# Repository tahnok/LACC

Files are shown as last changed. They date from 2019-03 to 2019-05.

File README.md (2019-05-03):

# L.A.C.C

## Laser-cut ATX Computer Case

This is a full sized ATX computer case you can laser cut (and probably cut using a CNC but I don't have one of those)

It should fit any ATX compliant motherboard, but I've only tried the one motherboard I have.

It has space for 3x 3.5" hard drives and a 2.5" hard drive, which are held by seperate 3d printed modules.

The entire design was done in Fusion 360. You can view it / download it [here](https://a360.co/2EToDJn) or use the LACC.f3z file attached.

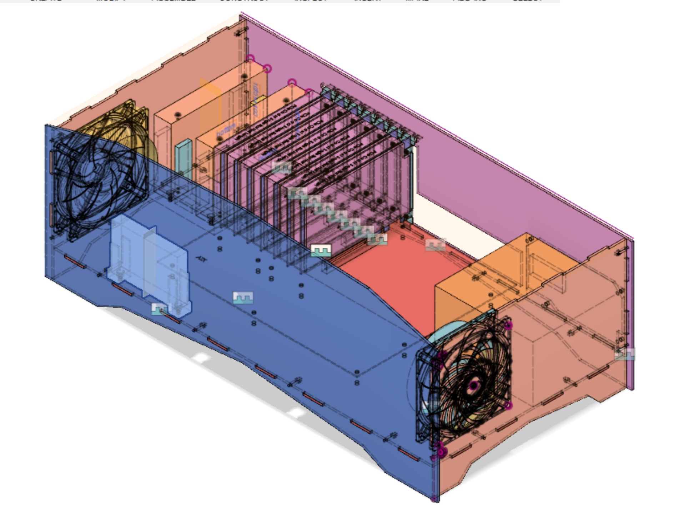
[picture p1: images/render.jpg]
render of case from fusion 360


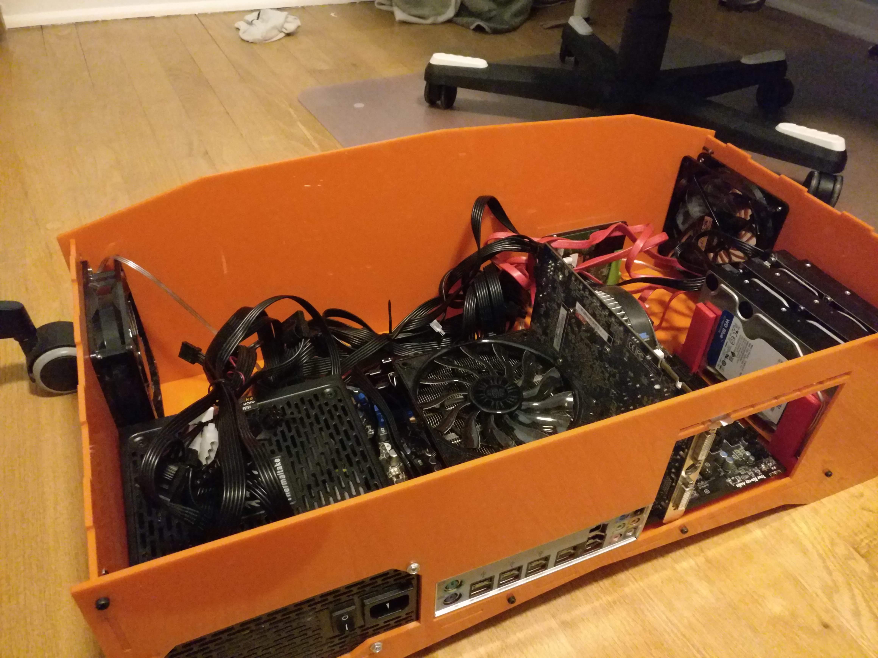
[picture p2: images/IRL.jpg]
actual built case


[more photos](https://photos.app.goo.gl/nMJByEWeSShFq6Pd6)

## Materials

### Case 
 - 5x sheets of 24" x 12" sheet of 1/8" or 3mm acrylic or MDF 
 - 26x M3 nuts
 - 20x M3x16 screws (for holding case together)
 - 6x M3x12 standoffs (for motherboard)
 - 6x M3x4 screws (for standoffs)
 - 2x 120mm Computer Fan
 - 4x 6-32 screws for ATX power supply

### Hard Drive Bays
 - 2x of the 3.5" drive holder parts
 - 2x of the 2.5" drive holder parts
 - 6x M3x10 screws
 - 6x M3 nuts

## Models Used

 - [Accurate Blank Motherboard & PCIe Card Models](https://smallformfactor.net/forum/resources/accurate-blank-motherboard-pcie-card-models.25/) by subtec
 - [120mm PC Case Fan](https://grabcad.com/library/120mm-pc-case-fan-1) by 
Ollie Keattch
 - Power supply (mine)
 - Hard Drive 2.5" and 3.5" (mine)

## License

 [Creative Commons Attribution-ShareAlike 4.0 International](https://creativecommons.org/licenses/by-sa/4.0/)

 You are free to use, sell and remix freely as long as any modifications you make are also shared under this same license

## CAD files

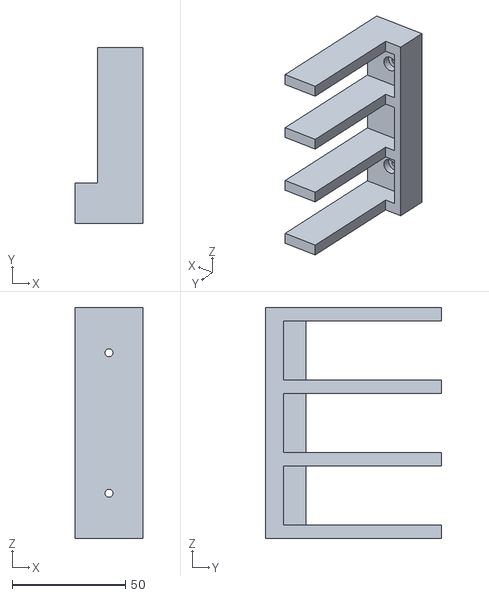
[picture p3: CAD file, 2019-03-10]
hard drive parts/hard drive holder 3-5.stl
30.0 x 78.0 x 102.1

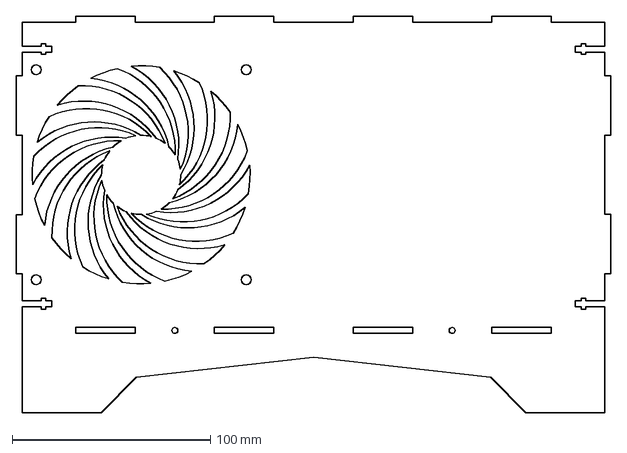
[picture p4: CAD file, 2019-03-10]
side.dxf
300.0 x 200.0 mm

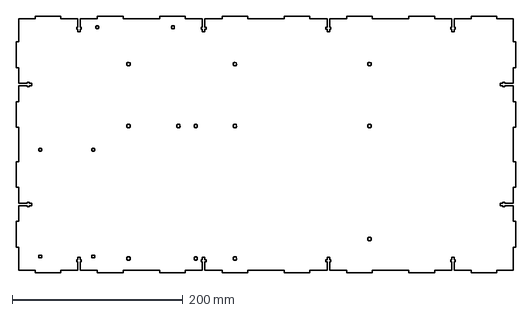
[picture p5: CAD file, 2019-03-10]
bottom.dxf
584.0 x 300.0 mm

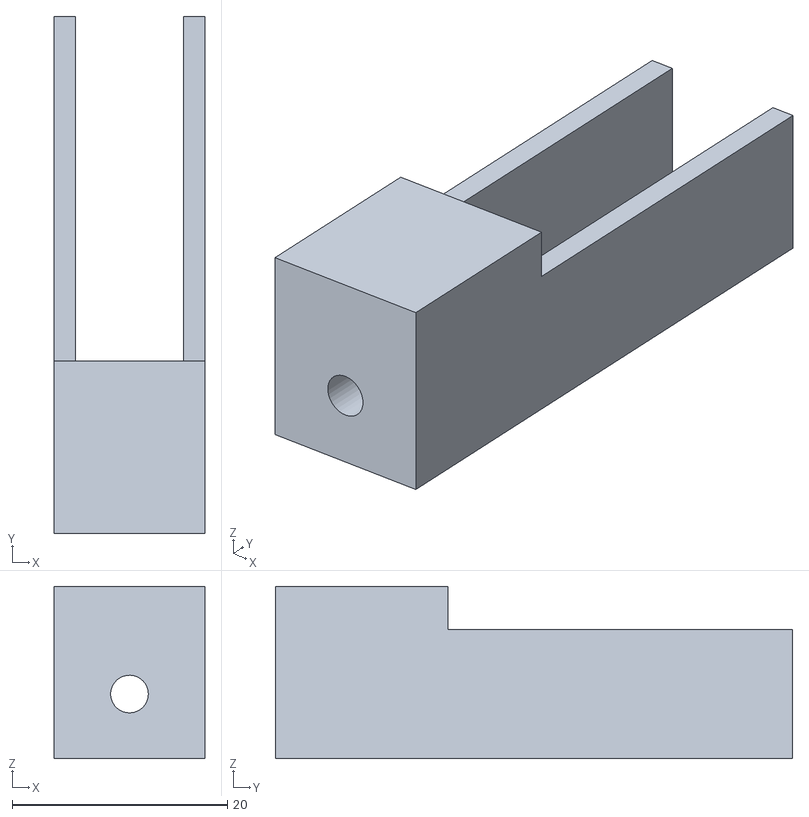
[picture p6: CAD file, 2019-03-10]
hard drive parts/hard drive holder 2-5.stl
14.0 x 48.0 x 16.0

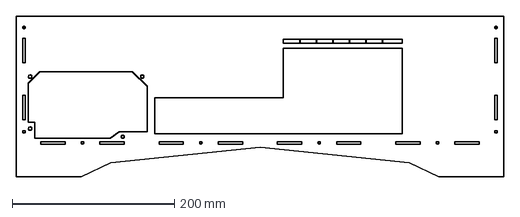
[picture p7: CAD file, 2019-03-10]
back.dxf
600.0 x 197.0 mm

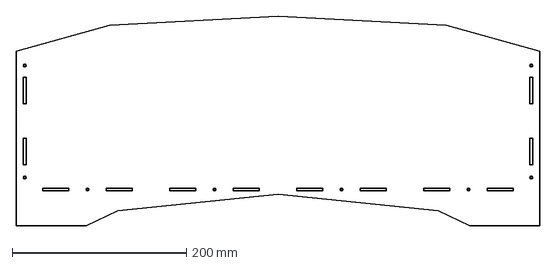
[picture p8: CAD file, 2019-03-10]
front.dxf
600.0 x 240.0 mm

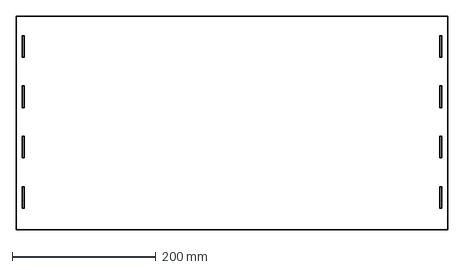
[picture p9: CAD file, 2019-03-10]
top.dxf
600.0 x 297.0 mm

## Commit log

2019-03-10 public LACC release
    [back.dxf, bottom.dxf, front.dxf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]
2019-03-10 case sensitive!
